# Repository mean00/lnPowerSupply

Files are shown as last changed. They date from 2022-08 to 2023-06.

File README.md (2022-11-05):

# lnPowerSupply
## Introduction
This is a very overengineered desktop power supply.
Small feature list :
- Powered by Lidl or Aldi battery back
- Current limiting (not very good)
- Large display (320x240)
- Large fonts 

## C++ vs Rust
The software comes in two flavors :
- C++
- Rust 

You can switch to either one (un)commenting the _SET(ENABLE_RUST True)_ in the top CmakeLists.txt

NB: The rust version contains bit of c++ (the lnArduino low level driver + the ina219 driver)

## Electrical Detail

You can use pretty much any DC/DC converter as a core, you need to adjust R2 depending on the feedback voltage
(see lnPowerSupply.pdf)
Be careful to stay below ~ 24v else the INA219 will blow.

Formula is ~ R2>420*FB 
 * FB=1.25=> R2>500
 * FB=0.8=>  R2>360...

The overal design is made of 3 parts :
- The DC/DC converter board itself
- The DC/DC control board, controlled over i2C
- The main board with a STM32 or GD32 driving the screen

## Why go to such a design ?
You need to have the control part close to the DC/DC
You need to have the SPI screen AWAY from the control board

[Small Youtube demo ](https://youtu.be/UPAjdyqt5LI)

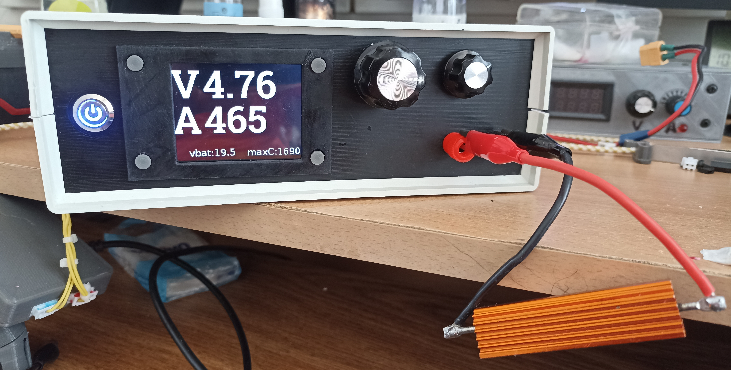
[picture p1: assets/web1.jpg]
front

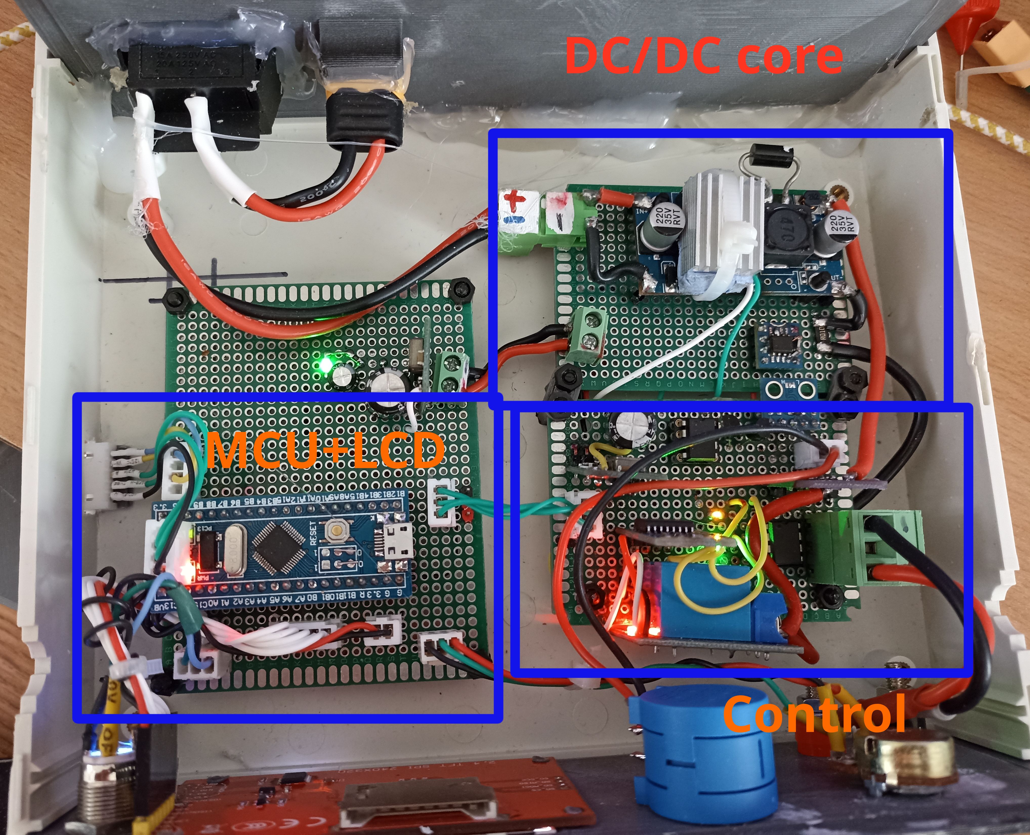
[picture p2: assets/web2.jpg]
internal


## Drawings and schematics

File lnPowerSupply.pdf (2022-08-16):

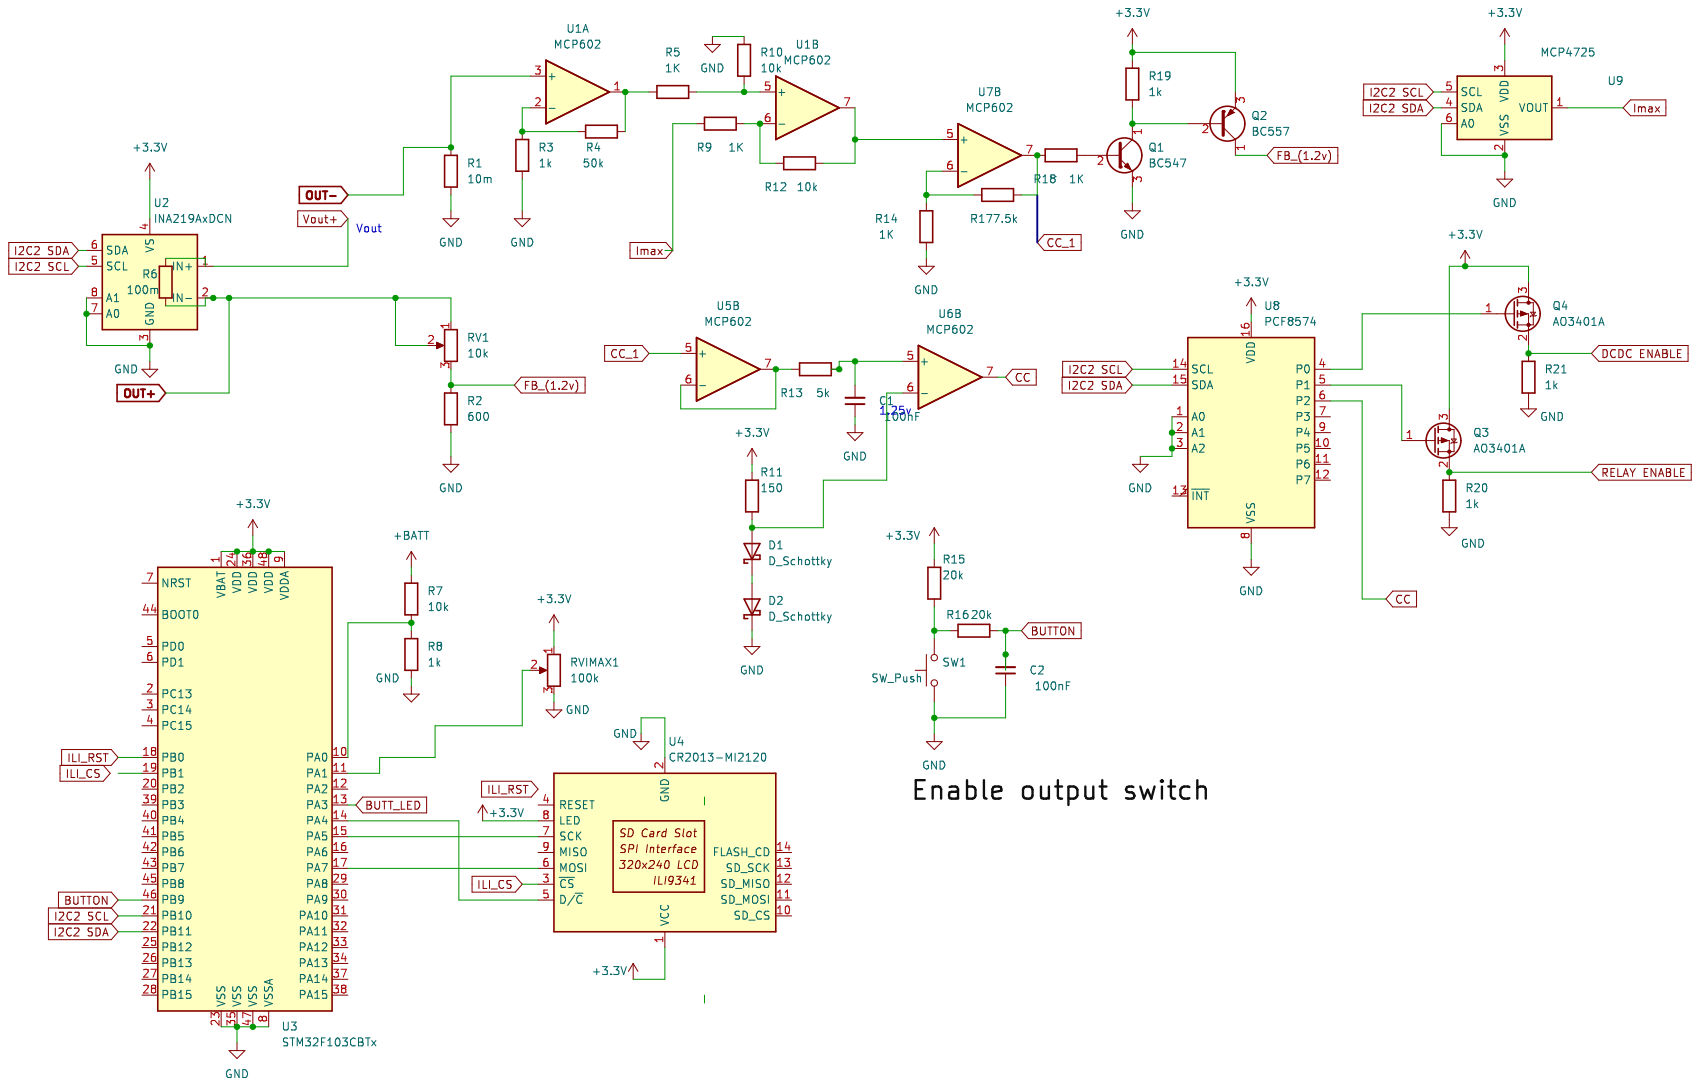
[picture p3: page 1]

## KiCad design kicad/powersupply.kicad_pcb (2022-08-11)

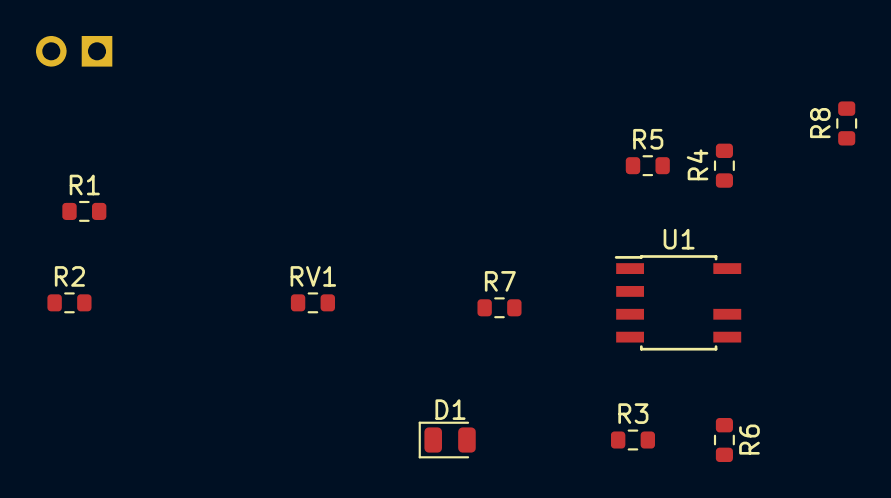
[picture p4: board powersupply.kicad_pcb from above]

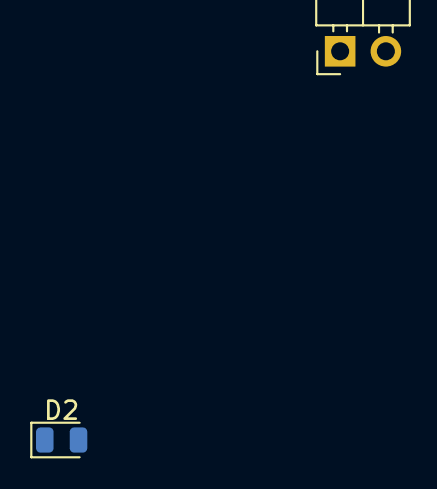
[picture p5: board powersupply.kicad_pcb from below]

Board: 2 copper layers, 13 parts (2 on the bottom side), 10 nets, no tracks yet.

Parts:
D1, D2: D_Schottky; D_0805_2012Metric
J1: Conn_01x02_Female; PinHeader_1x02_P2.54mm_Horizontal
R1: 10m; R_0603_1608Metric
R2: 3.3k; R_0603_1608Metric
R3: 1k; R_0603_1608Metric
R4, R6, R8: 50k; R_0603_1608Metric
R5, R7: 1K; R_0603_1608Metric
RV1: 100k; R_0603_1608Metric
U1: LM358; SOIC-8-N7_3.9x4.9mm_P1.27mm

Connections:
GND: R1.2, R2.2, R3.2, R6.2
unnamed: D1.1 (K), D2.1 (K)
unnamed: D1.2 (A), R8.2
unnamed: D2.2 (A), R2.1
unnamed: J1.1, RV1.1, RV1.2
unnamed: J1.2, R1.1, U1.3 (+)
unnamed: R3.1, R4.1, U1.2 (-)
unnamed: R4.2, R5.1, U1.1
unnamed: R5.2, R6.1, U1.5 (+)
unnamed: R7.1, R8.1, U1.6 (-)

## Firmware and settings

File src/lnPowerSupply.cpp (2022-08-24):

/**
 *  Massively over engineered power supply
 * 
 
 * 
 */
#include "lnArduino.h"
#include "lnADC.h"
#include "lnHardwareConfiguration.h"
#include "lnI2CTask.h"
#include "lnDisplay.h"

#define INA_MA_FLOOR 24
#define ADC_SAMPLE 8

enum otherEvent
{
    EnableButtonEvent=128,
};

//----------

extern lnI2cTask *createI2cTask(lnI2cTask::signalCb *c);
void stopLowVoltage();
void onOffCallback(lnPin pin, void *cookie);

xFastEventGroup *eventGroup;

//----------

lnTimingAdc         *adc;
lnI2cTask           *tsk;

bool                outputEnabled=false;

const lnPin pins[2]={PS_PIN_VBAT, PS_PIN_MAX_CURRENT};

/**
 * 
 */
void setup()
{
    Logger("Setuping up Power Supply...\n");
   
    lnPinMode(PS_PIN_VBAT,lnADC_MODE);
    lnPinMode(PS_PIN_MAX_CURRENT,lnADC_MODE);

    lnPinMode(LN_SYSTEM_LED,lnOUTPUT);
    lnPinMode(PIN_LED,lnOUTPUT);
    lnPinMode(PIN_SWITCH,lnINPUT_PULLUP);

    lnExtiAttachInterrupt(PIN_SWITCH, LN_EDGE_FALLING, onOffCallback, NULL);
    lnExtiEnableInterrupt(PIN_SWITCH);
  
    lnDisplay::init();
    adc=new lnTimingAdc(0);
    adc->setSource(3,3,1000,2,pins);

    eventGroup = new xFastEventGroup;
}

/**
 * 
 */
void onOffCallback(lnPin pin, void *cookie)
{
    outputEnabled^=1;    
    lnExtiDisableInterrupt(PIN_SWITCH);
    eventGroup->setEvents(EnableButtonEvent);
}
/**
 * \fn runAdc
 * \brief Average ADC reading over ADC_SAMPLE samples
 * Convert ADC reading to vbat and maxCurrent (in mA)
 */
void runAdc(float &fvbat, int &maxCurrentSlopped)
{
    static uint16_t output[ADC_SAMPLE*2];
    adc->multiRead(ADC_SAMPLE,output); 
    uint16_t *p=output;
    int max0=0,max1=0;
    for(int i=0;i<ADC_SAMPLE;i++)
    {
            max0+=*p++;
            max1+=*p++;
    }
    int vbat, maxCurrent;
    vbat = (max0 + ((ADC_SAMPLE-1)/2))/ADC_SAMPLE;
    maxCurrent = (max1 + ((ADC_SAMPLE-1)/2))/ADC_SAMPLE;

    fvbat=(float)vbat;
    fvbat=fvbat*9.;
    fvbat/=1000.;
    
    maxCurrent=maxCurrent*maxCurrent;
    // 0..4095 -> 0.. 4A amp=val*1.5+50
    // so max=4000/1.5=2660
    maxCurrent/=6300; // 0..4000
    maxCurrent-=(maxCurrent&7);
    maxCurrent+=50;
    maxCurrentSlopped=maxCurrent;
}
/**
 * 
 */
void i2cCb(uint32_t signal)
{
    eventGroup->setEvents(signal);
}
/**
 * 
 */
 extern "C" void rnLoop(void);
void loop()
{
    rnLoop();
    eventGroup->takeOwnership();
    tsk=createI2cTask(i2cCb);
    xDelay(20); // let it start    
    float vbat;
    int imaxAmp, lastMaxCurrent=-1;;
    
    runAdc(vbat, imaxAmp);
    if(vbat<PS_MIN_VBAT)
    {
        stopLowVoltage();
    }    

    tsk->setDCEnable(true);
    tsk->setOutputEnable(false); 
    lnDigitalWrite(PIN_LED,true);

   while(1)
   {
        int event=eventGroup->waitEvents(0xfff,100);
        lnDigitalToggle(LN_SYSTEM_LED);            

        int   current=tsk->getCurrent();
        bool  cc=tsk->getCCLimited();


        if(event & EnableButtonEvent)
        {
            lnDigitalWrite(PIN_LED,!outputEnabled);
            tsk->setOutputEnable(outputEnabled);
            xDelay(20);
            lnExtiEnableInterrupt(PIN_SWITCH);
        }

        float voltage=tsk->getVoltage();
        if(event & (lnI2cTask::VoltageChangeEvent | lnI2cTask::CCChangeEvent | lnI2cTask::CurrentChangeEvent))
        {
            float correction=WIRE_RESISTANCE_MOHM;
            correction=correction*current;
            correction/=1000000.;
            voltage-=correction;
            lnDisplay::displayVoltage( cc,  voltage);
            float power=voltage*(float)current;
            power/=1000.;
            lnDisplay::displayPower( cc,  power);
        }
        if(event & (lnI2cTask::CurrentChangeEvent))
        {
            lnDisplay::displayCurrent(current);
        }

       
        runAdc(vbat, imaxAmp);
        lnDisplay::displayVbat( vbat);

        if(vbat<PS_MIN_VBAT_CRIT)
        {
            stopLowVoltage();
        }

        int delta=lastMaxCurrent- imaxAmp;
        if(delta<0) delta=-delta;
        if(delta>10)
        {
            lastMaxCurrent=imaxAmp;
            float d=imaxAmp;
            d/=1.5;
            d-=25;
            if(d<0) d=0.;
            
            tsk->setMaxCurrent(d);
            lnDisplay::displayMaxCurrent(imaxAmp);
        }
    }
}
/**
 * 
 */
void stopLowVoltage()
{
    tsk->setOutputEnable(false);
    tsk->setDCEnable(false);
    lnDisplay::banner("LOW BATTERY");
    while(1)
    {
        lnDigitalToggle(LN_SYSTEM_LED);    
        lnDigitalToggle(PIN_LED);
        xDelay(20);
    }
}

// EOF

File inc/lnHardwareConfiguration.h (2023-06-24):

#pragma once

#define PS_I2C_INSTANCE     1

// INA
#define INA_SHUNT_VALUE     106 // 106 mOhm

// screen 
#define ILI_SPI_INSTANCE    0
#define ILI_PIN_DC          PA4
#define ILI_PIN_CS          PB1
#define ILI_PIN_RESET       PB0

#define PIN_LED             PA3
#define PIN_SWITCH          PB9

#define PS_PIN_VBAT         PA0
#define PS_PIN_MAX_CURRENT  PA1
#define PS_INTERNAL_RESISTANCE_MILLIOHM 300 // error on voltage is  ~ 50 mV

// IO Expander
#define IO_EXPANDER_ADDRESS         32
#define IO_EXPANDER_DC_ENABLE       0
#define IO_EXPANDER_RELAY_ENABLE    1
#define IO_EXPANDER_CC_MODE         2

// PCF8574
#define PCF8574_ADDRESS         32
#define PCF8574_DCDC_ENABLE     1 // out
#define PCF8574_RELAY_ENABLE    2 // out
#define PCF8574_CC_MODE         4 // in

// Tasks 
#define I2C_TASK_PRIORITY 2
#define I2C_STACK_SIZE    1024


// VBAT limit
#define PS_MIN_VBAT         15. // at start
#define PS_MIN_VBAT_CRIT    14. // anytime

//
#define WIRE_RESISTANCE_MOHM  220 // wire resistance

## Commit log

2022-08-11 sort of basic version
    [powersupply.kicad_pcb, powersupply.kicad_sch]
2022-08-13 basic power supply
    [powersupply.kicad_sch]
2022-08-13 take wires resistance into account
2022-08-14 add schematic
2022-08-15 change display a bit, add power
2022-08-15 add additional glyphs, redo display a bit, switch to semi signaled based refresh
2022-08-16 update PDF
    [powersupply.kicad_sch]
2022-08-16 annotate components
    [powersupply.kicad_sch]
2022-08-21 more c++/rust glue
2022-09-03 by default rust is disabled + update kicad
    [powersupply.kicad_sch]
2022-09-03 dont double initialize the i2c task, have low bat threshold higer, remove dead code
2022-09-10 switch to clang, cleanup bindgen stuff
2022-09-10 switch to rn instead of ln
2022-09-18 use intermediate safe binding
    [app.rs, settings.rs]
2022-09-27 fix build of C version
    [lnPowerSupply.cpp]
2022-10-25 begin switching to rust ILI
2022-11-05 fix printout
2022-12-11 switch to simpler_gfx font
2022-12-18 add task to rust bindings
    [app.rs, lib.rs, taist.rs]
2022-12-18 flesh out i2c task
2022-12-22 use a void* to avoid endless headache
    [app.rs, slave_task.rs]
2022-12-23 use dirty c callback to avoid over complicated proper fix
    [app.rs, settings.rs, slave_task.rs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]
2022-12-23 cleanup the rs part, we dont need those C++ libs in that case
2022-12-23 switch off lto through rust cflags
2022-12-24 working ina219, fix i2c error
    [lib.rs]
2022-12-24 display a small battery icon to warn we are going low
2022-12-24 add battery icons
2022-12-25 avoit the front LED flashing at start
2023-02-06 ili : take gauge fix
    [app.rs]
2023-02-08 arm: update to clang17
2023-06-24 C++ version : i2c task explicitely set the stack size to 1024 and avoid stack overflow
    [lnHardwareConfiguration.h, lnI2CTask.cpp]
2023-10-29 update to newer lnArduino + rust binding
    [app.rs]
2024-05-05 partial update to newer rust binding
    [app.rs]
2024-05-08 update kicad
    [powersupply.kicad_sch]
2024-05-08 debug:move uart to uart1, not uart0
2025-03-01 update ili driver
2025-10-22 update kicad schematic with latched button
    [powersupply.kicad_sch]
2025-10-22 switch to rtt logging
2025-10-22 switch to latched button
2025-10-22 rename to ButtonEvent as it is used both for on and off
2025-10-26 complete schematic
    [power.kicad_sch, powersupply.kicad_sch]
2025-10-28 update esprit to get newer i2c driver, use GD32F3 as default
2025-10-28 button is a pullup, not a pulldown
2025-10-31 update esprit to get the updated i2c driver
